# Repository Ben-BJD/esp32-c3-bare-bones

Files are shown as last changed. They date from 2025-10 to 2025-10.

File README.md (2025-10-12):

# ESP32-C3 - Bare Bones DevKitM - KiCAD Source Files

This project is a work in progress.

## Goal: 

Create a simplified custom PCB based on the [ESP32-C3-DevKitM-1](https://docs.espressif.com/projects/esp-dev-kits/en/latest/esp32c3/esp32-c3-devkitm-1/user_guide.html)

This board is designed to consume as little power as possible while in deep sleep. Ideally 5uF as per the ESP-32 [datasheet](https://www.espressif.com/sites/default/files/documentation/esp32-c3-mini-1_datasheet_en.pdf). To this end the Voltage Regulator, RGB LED, Power LED and USB-UART interface have been removed. Leaving just the MCU, Reset/Boot button and header pins.

The board will need to be powered directly with a power source between 3.0 and 3.6v. It is important that the voltage never exceed 3.6v. Regular Lipo batteries typically have a maximum voltage of 4.2v so are not suitable.

This board was designed to be powered by a 3.2v LiFePO4 battery. LiFePO4 batteries can reach 3.65v when fully charged. A BMS set to cut off at 3.6V or slightly lower will be necesary.

The board will need to be programmed with an FDTI programmer as there is no USB interface.

## Resources:

* [ESP32-C3-MINI-1 MCU Datasheet](https://www.espressif.com/sites/default/files/documentation/esp32-c3-mini-1_datasheet_en.pdf)
* [ESP32-C3-DevKitM-1 Docs](https://docs.espressif.com/projects/esp-dev-kits/en/latest/esp32c3/esp32-c3-devkitm-1/user_guide.html)
* [ESP32-C3-DevKitM-1 Schematic](https://dl.espressif.com/dl/schematics/SCH_ESP32-C3-DEVKITM-1_V1_20200915A.pdf)

## Schematic:

[PDF Version](esp32-c3-bare-bones-schematic.pdf)

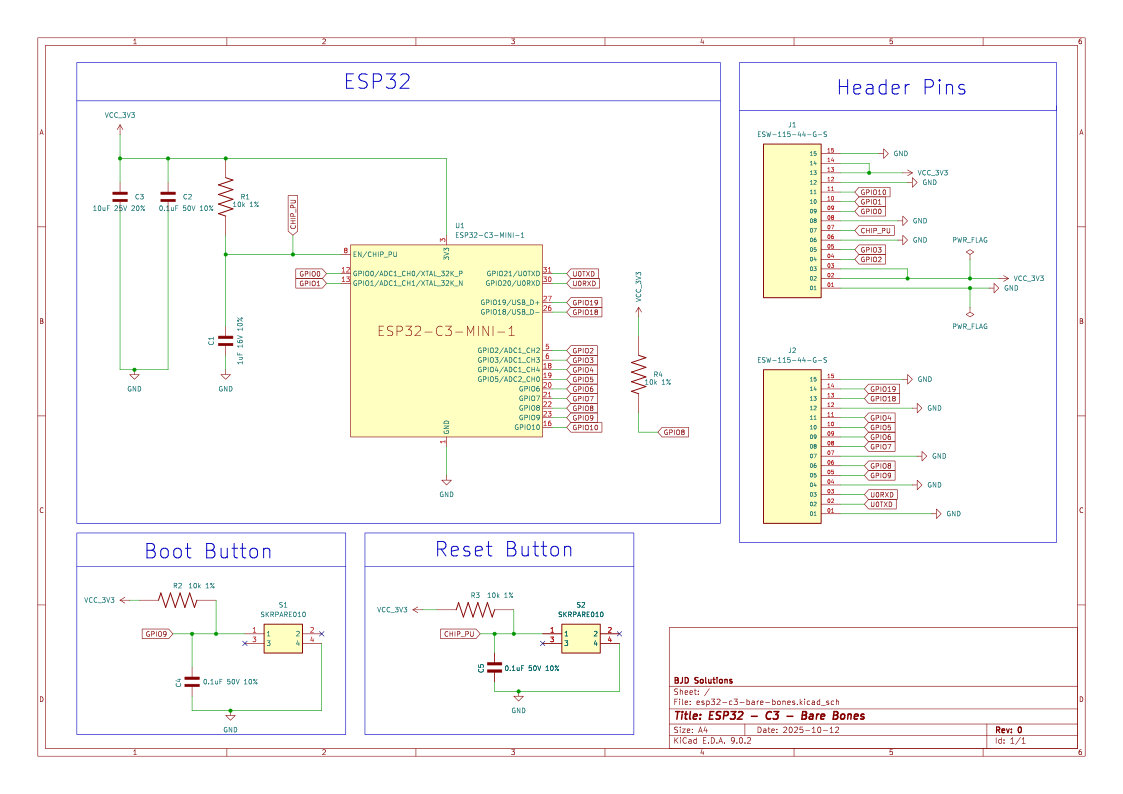
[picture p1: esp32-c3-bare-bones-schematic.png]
Board schematic


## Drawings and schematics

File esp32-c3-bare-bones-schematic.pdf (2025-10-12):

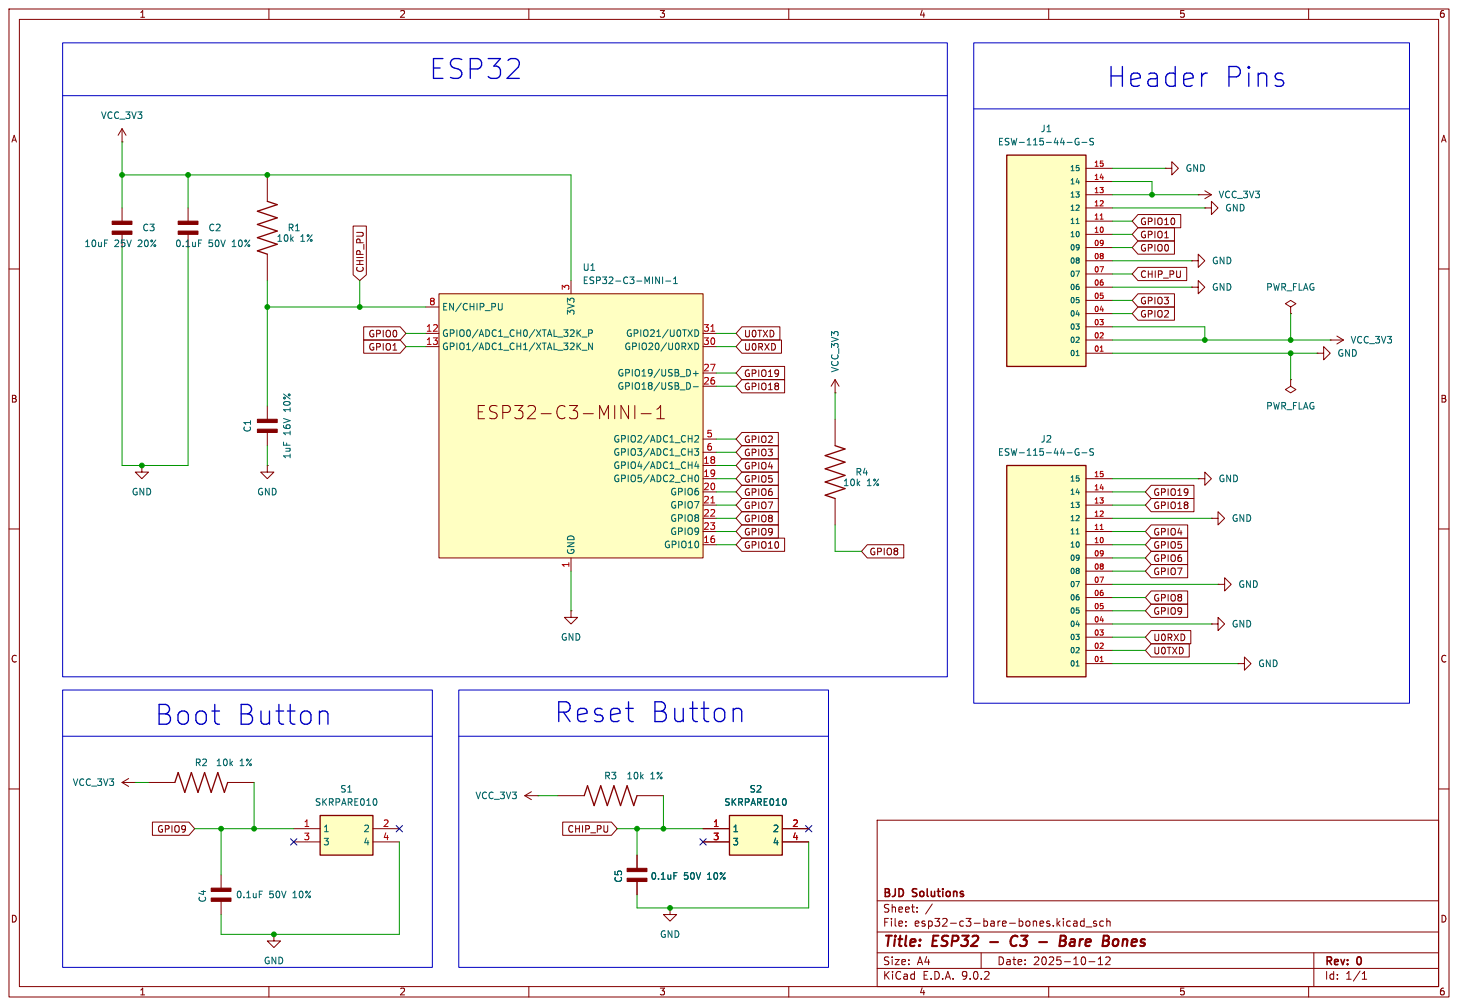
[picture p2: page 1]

File: esp32-c3-bare-bones.kicad_sch Sheet: / BJD Solutions

Id: 1/1 Title: ESP32 - C3 - Bare Bones

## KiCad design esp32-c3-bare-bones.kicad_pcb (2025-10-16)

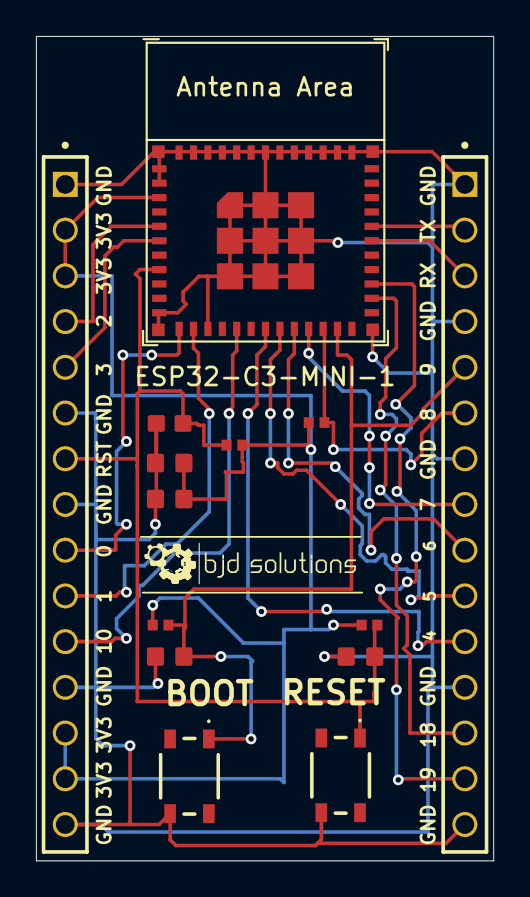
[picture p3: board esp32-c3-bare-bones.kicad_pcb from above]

Board: 2 copper layers, 25.4 x 45.8 mm, 14 parts (0 on the bottom side), 18 nets.

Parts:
BOOT: SKRPARE010
C1: 1uF 16V 10%; CAPC1608X90N
C2, C4, C5: 0.1uF 50V 10%; CAPC1608X100N
C3: 10uF 25V 20%; CAPC1608X100N
ESP32-C3-MINI-1: ESP32-C3-MINI-1
J1, J2: ESW-115-44-G-S; SAMTEC_ESW-115-44-G-S
R1, R2, R3, R4: 10k 1%; RESC1005X37N
RESET: SKRPARE010

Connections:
CHIP_PU: C1.2, C5.2, ESP32-C3-MINI-1.8 (EN/CHIP_PU), J1.07, R1.1, R3.2, RESET.1
GND: BOOT.4, C1.1, C2.1, C3.1, C4.1, C5.1, ESP32-C3-MINI-1.1 (GND), ESP32-C3-MINI-1.2 (GND), ESP32-C3-MINI-1.11 (GND), ESP32-C3-MINI-1.14 (GND), ESP32-C3-MINI-1.36 (GND), ESP32-C3-MINI-1.37 (GND), ESP32-C3-MINI-1.38 (GND), ESP32-C3-MINI-1.39 (GND), ESP32-C3-MINI-1.40 (GND), ESP32-C3-MINI-1.41 (GND), ESP32-C3-MINI-1.42 (GND), ESP32-C3-MINI-1.43 (GND), ESP32-C3-MINI-1.44 (GND), ESP32-C3-MINI-1.45 (GND), ESP32-C3-MINI-1.46 (GND), ESP32-C3-MINI-1.47 (GND), ESP32-C3-MINI-1.48 (GND), ESP32-C3-MINI-1.49 (GND), ESP32-C3-MINI-1.50 (GND), ESP32-C3-MINI-1.51 (GND), ESP32-C3-MINI-1.52 (GND), ESP32-C3-MINI-1.53 (GND), J1.01, J1.06, J1.08, J1.12, J1.15, J2.01, J2.04, J2.07, J2.12, J2.15, RESET.4
GPIO0: ESP32-C3-MINI-1.12 (GPIO0/ADC1_CH0/XTAL_32K_P), J1.09
GPIO1: ESP32-C3-MINI-1.13 (GPIO1/ADC1_CH1/XTAL_32K_N), J1.10
GPIO2: ESP32-C3-MINI-1.5 (GPIO2/ADC1_CH2), J1.04
GPIO3: ESP32-C3-MINI-1.6 (GPIO3/ADC1_CH3), J1.05
GPIO4: ESP32-C3-MINI-1.18 (GPIO4/ADC1_CH4), J2.11
GPIO5: ESP32-C3-MINI-1.19 (GPIO5/ADC2_CH0), J2.10
GPIO6: ESP32-C3-MINI-1.20 (GPIO6), J2.09
GPIO7: ESP32-C3-MINI-1.21 (GPIO7), J2.08
GPIO8: ESP32-C3-MINI-1.22 (GPIO8), J2.06, R4.2
GPIO9: BOOT.1, C4.2, ESP32-C3-MINI-1.23 (GPIO9), J2.05, R2.2
GPIO10: ESP32-C3-MINI-1.16 (GPIO10), J1.11
GPIO18: ESP32-C3-MINI-1.26 (GPIO18/USB_D-), J2.13
GPIO19: ESP32-C3-MINI-1.27 (GPIO19/USB_D+), J2.14
U0RXD: ESP32-C3-MINI-1.30 (GPIO20/U0RXD), J2.03
U0TXD: ESP32-C3-MINI-1.31 (GPIO21/U0TXD), J2.02
VCC_3V3: C2.2, C3.2, ESP32-C3-MINI-1.3 (3V3), J1.02, J1.03, J1.13, J1.14, R1.2, R2.1, R3.1, R4.1
